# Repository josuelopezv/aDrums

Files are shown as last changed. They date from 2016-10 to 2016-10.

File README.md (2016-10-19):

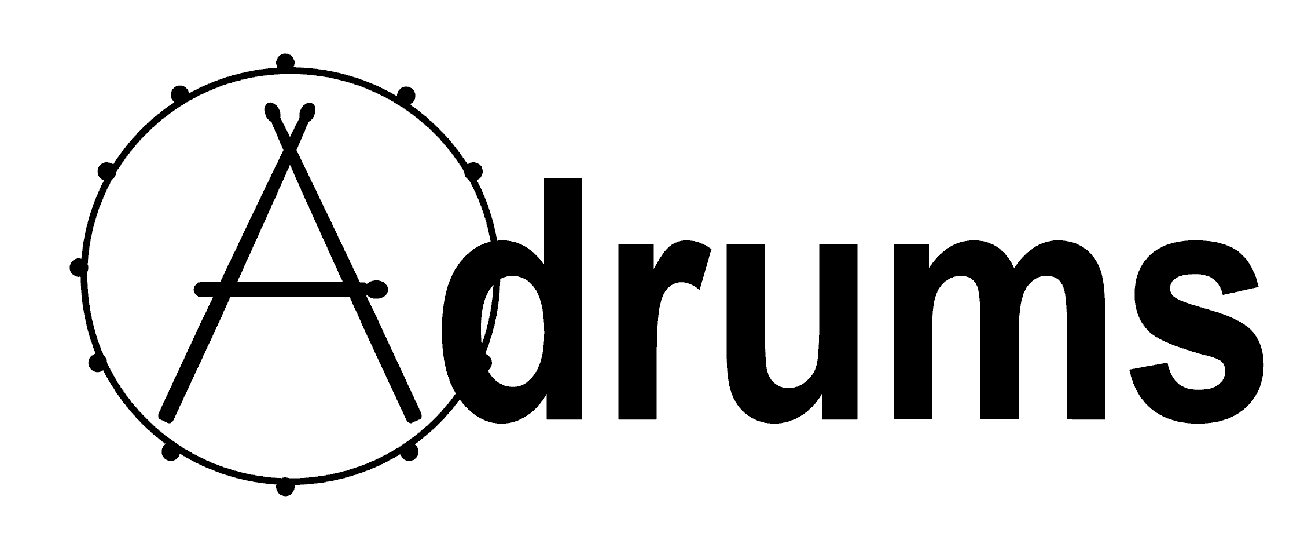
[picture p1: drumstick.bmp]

[]()

**A-Drums** is a completly Open Source, Advance Drum MIDI Trigger based on Arduino Leonardo Micro Pro. The idea came after seeing solutions like MegaDRUM but it was closed source. The hardware is open source as well including Eagle Schematics and Eagle Board Layout. It is easy to use and build while being a robust product.

## Features
* 37 Input Triggers with 18 small audio jack connectors
* It's a simple USB Device without need to install any drivers to run it reports as a MIDI Device
* Positional sensing
* Fully Customizable
* Small Form Factor
* Comes with a nice easy to use GUI Manager
* Saves settings to EEPROM
* Compatible with EZ Drummer, Addictive Drums, Fruity Loops, etc.
* Cross Platform (Windows/Linux/Mac)
* Can be configured from Android or iOS

## Price and Bill of Materials
- [Arduino Leonardo Pro Micro](https://www.sparkfun.com/products/12640)		$4.13
- PCB Board		$8.30
- [Audio Jacks](http://www.ebay.com/itm/141778008302?_trksid=p2060353.m2749.l2649&ssPageName=STRK%3AMEBIDX%3AIT)		$6.87
- [Rest of electronics]		$2.5

### Total **$19.24**

I will be adding tutorials on how to build the DIY 3D Printed Drum Set, how to connect with EZ Drummer and Addictive Drums using ASIO4ALL, and aDrums Manager User Manual

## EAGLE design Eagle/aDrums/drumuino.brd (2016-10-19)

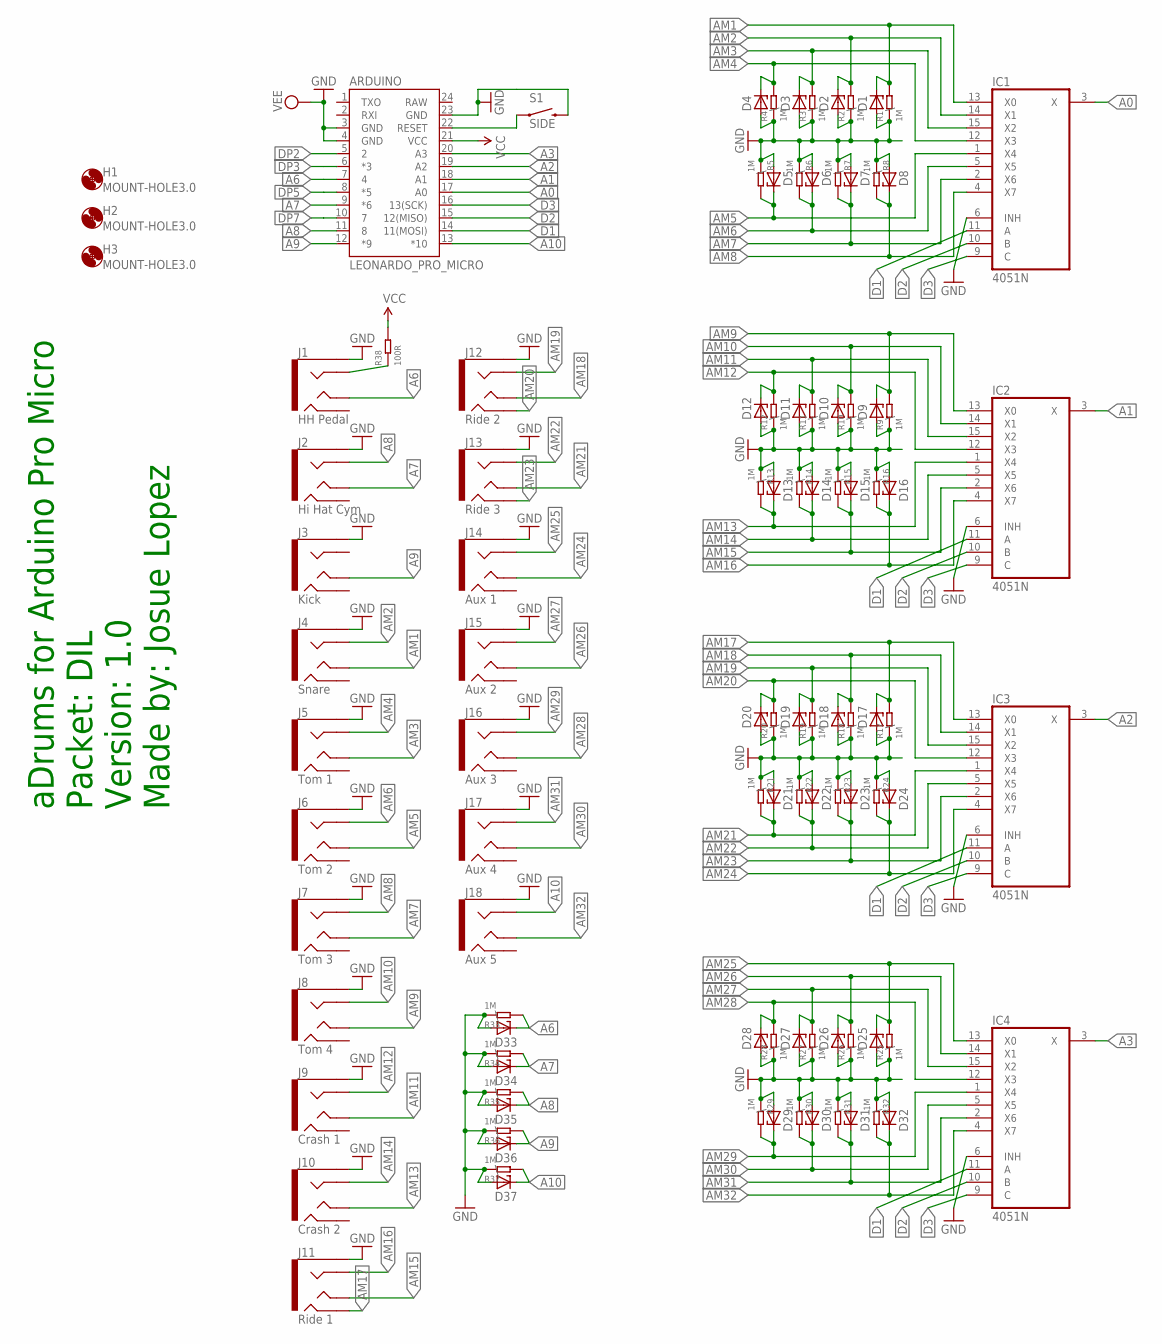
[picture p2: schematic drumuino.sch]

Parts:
ARDUINO: LEONARDO_PRO_MICRO; ARDUINO_PRO_MICRO
D1, D2, D3, D4, D5, D6, D7, D8, D9, D10, D11, D12, D13, D14, D15, D16, D17, D18, D19, D20, D21, D22, D23, D24, D25, D26, D27, D28, D29, D30, D31, D32, D33, D34, D35, D36, D37: \; DO41-7.6
H1, H2, H3: MOUNT-HOLE3.0; 3,0
IC1, IC2, IC3, IC4: 4051N; DIL16
J1: HH Pedal; AUDIO-JACK-TRRS-DIL
J2: Hi Hat Cym; AUDIO-JACK-TRRS-DIL
J3: Kick; AUDIO-JACK-TRRS-DIL
J4: Snare; AUDIO-JACK-TRRS-DIL
J5: Tom 1; AUDIO-JACK-TRRS-DIL
J6: Tom 2; AUDIO-JACK-TRRS-DIL
J7: Tom 3; AUDIO-JACK-TRRS-DIL
J8: Tom 4; AUDIO-JACK-TRRS-DIL
J9: Crash 1; AUDIO-JACK-TRRS-DIL
J10: Crash 2; AUDIO-JACK-TRRS-DIL
J11: Ride 1; AUDIO-JACK-TRRS-DIL
J12: Ride 2; AUDIO-JACK-TRRS-DIL
J13: Ride 3; AUDIO-JACK-TRRS-DIL
J14: Aux 1; AUDIO-JACK-TRRS-DIL
J15: Aux 2; AUDIO-JACK-TRRS-DIL
J16: Aux 3; AUDIO-JACK-TRRS-DIL
J17: Aux 4; AUDIO-JACK-TRRS-DIL
J18: Aux 5; AUDIO-JACK-TRRS-DIL
R1, R2, R3, R4, R5, R6, R7, R8, R9, R10, R11, R12, R13, R14, R15, R16, R17, R18, R19, R20, R21, R22, R23, R24, R25, R26, R27, R28, R29, R30, R31, R32, R33, R34, R35, R36, R37: 1M; R0207_7
R38: 100R; R0207_7
S1: SIDE; TACTILE-PTH-SIDEEZ

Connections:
A0: ARDUINO.17 (A0), IC1.3 (X)
A1: ARDUINO.18 (A1), IC2.3 (X)
A2: ARDUINO.19 (A2), IC3.3 (X)
A3: ARDUINO.20 (A3), IC4.3 (X)
A6: ARDUINO.7 (4), D33.C, J1.TIP, R33.2
A7: ARDUINO.9 (*6), D34.C, J2.TIP, R34.2
A8: ARDUINO.11 (8), D35.C, J2.RING1, R35.2
A9: ARDUINO.12 (*9), D36.C, J3.TIP, R36.2
A10: ARDUINO.13 (*10), D37.C, J18.RING1, R37.2
AM1: D1.C, IC1.13 (X0), J4.TIP, R1.2
AM2: D2.C, IC1.14 (X1), J4.RING1, R2.2
AM3: D3.C, IC1.15 (X2), J5.TIP, R3.2
AM4: D4.C, IC1.12 (X3), J5.RING1, R4.2
AM5: D5.C, IC1.1 (X4), J6.TIP, R5.2
AM6: D6.C, IC1.5 (X5), J6.RING1, R6.2
AM7: D7.C, IC1.2 (X6), J7.TIP, R7.2
AM8: D8.C, IC1.4 (X7), J7.RING1, R8.2
AM9: D9.C, IC2.13 (X0), J8.TIP, R9.2
AM10: D10.C, IC2.14 (X1), J8.RING1, R10.2
AM11: D11.C, IC2.15 (X2), J9.TIP, R11.2
AM12: D12.C, IC2.12 (X3), J9.RING1, R12.2
AM13: D13.C, IC2.1 (X4), J10.TIP, R13.2
AM14: D14.C, IC2.5 (X5), J10.RING1, R14.2
AM15: D15.C, IC2.2 (X6), J11.TIP, R15.2
AM16: D16.C, IC2.4 (X7), J11.RING1, R16.2
AM17: D17.C, IC3.13 (X0), J11.RING2, R17.2
AM18: D18.C, IC3.14 (X1), J12.TIP, R18.2
AM19: D19.C, IC3.15 (X2), J12.RING1, R19.2
AM20: D20.C, IC3.12 (X3), J12.RING2, R20.2
AM21: D21.C, IC3.1 (X4), J13.TIP, R21.2
AM22: D22.C, IC3.5 (X5), J13.RING1, R22.2
AM23: D23.C, IC3.2 (X6), J13.RING2, R23.2
AM24: D24.C, IC3.4 (X7), J14.TIP, R24.2
AM25: D25.C, IC4.13 (X0), J14.RING1, R25.2
AM26: D26.C, IC4.14 (X1), J15.TIP, R26.2
AM27: D27.C, IC4.15 (X2), J15.RING1, R27.2
AM28: D28.C, IC4.12 (X3), J16.TIP, R28.2
AM29: D29.C, IC4.1 (X4), J16.RING1, R29.2
AM30: D30.C, IC4.5 (X5), J17.TIP, R30.2
AM31: D31.C, IC4.2 (X6), J17.RING1, R31.2
AM32: D32.C, IC4.4 (X7), J18.TIP, R32.2
D1: ARDUINO.14 (11(MOSI)), IC1.11 (A), IC2.11 (A), IC3.11 (A), IC4.11 (A)
D2: ARDUINO.15 (12(MISO)), IC1.10 (B), IC2.10 (B), IC3.10 (B), IC4.10 (B)
D3: ARDUINO.16 (13(SCK)), IC1.9 (C), IC2.9 (C), IC3.9 (C), IC4.9 (C)
DP2: ARDUINO.5 (2)
DP3: ARDUINO.6 (*3)
DP5: ARDUINO.8 (*5)
DP7: ARDUINO.10 (7)
GND: ARDUINO.3 (GND), ARDUINO.4 (GND), ARDUINO.23 (GND), D1.A, D2.A, D3.A, D4.A, D5.A, D6.A, D7.A, D8.A, D9.A, D10.A, D11.A, D12.A, D13.A, D14.A, D15.A, D16.A, D17.A, D18.A, D19.A, D20.A, D21.A, D22.A, D23.A, D24.A, D25.A, D26.A, D27.A, D28.A, D29.A, D30.A, D31.A, D32.A, D33.A, D34.A, D35.A, D36.A, D37.A, IC1.6 (INH), IC1.7 (VEE), IC1.8 (GND), IC2.6 (INH), IC2.7 (VEE), IC2.8 (GND), IC3.6 (INH), IC3.7 (VEE), IC3.8 (GND), IC4.6 (INH), IC4.7 (VEE), IC4.8 (GND), J1.2EARTH (EARTH), J1.EARTH, J2.2EARTH (EARTH), J2.EARTH, J3.2EARTH (EARTH), J3.EARTH, J4.2EARTH (EARTH), J4.EARTH, J5.2EARTH (EARTH), J5.EARTH, J6.2EARTH (EARTH), J6.EARTH, J7.2EARTH (EARTH), J7.EARTH, J8.2EARTH (EARTH), J8.EARTH, J9.2EARTH (EARTH), J9.EARTH, J10.2EARTH (EARTH), J10.EARTH, J11.2EARTH (EARTH), J11.EARTH, J12.2EARTH (EARTH), J12.EARTH, J13.2EARTH (EARTH), J13.EARTH, J14.2EARTH (EARTH), J14.EARTH, J15.2EARTH (EARTH), J15.EARTH, J16.2EARTH (EARTH), J16.EARTH, J17.2EARTH (EARTH), J17.EARTH, J18.2EARTH (EARTH), J18.EARTH, R1.1, R2.1, R3.1, R4.1, R5.1, R6.1, R7.1, R8.1, R9.1, R10.1, R11.1, R12.1, R13.1, R14.1, R15.1, R16.1, R17.1, R18.1, R19.1, R20.1, R21.1, R22.1, R23.1, R24.1, R25.1, R26.1, R27.1, R28.1, R29.1, R30.1, R31.1, R32.1, R33.1, R34.1, R35.1, R36.1, R37.1, S1.2
HHC_TIP: J1.RING1, R38.1
unnamed: ARDUINO.22 (RESET), S1.1
VCC: ARDUINO.21 (VCC), IC1.16 (VCC), IC2.16 (VCC), IC3.16 (VCC), IC4.16 (VCC), R38.2

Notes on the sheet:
aDrums for Arduino Pro Micro Packet: DIL Version: 1.0 Made by: Josue Lopez

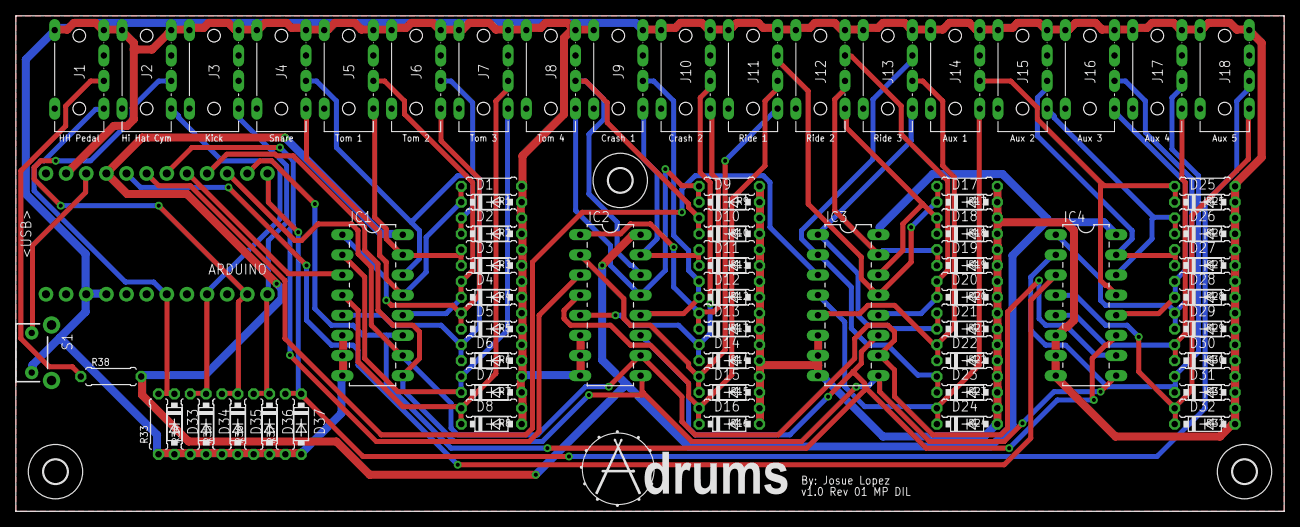
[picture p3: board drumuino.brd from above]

Board: 2 copper layers, 160.0 x 62.5 mm, 102 parts (0 on the bottom side), 48 nets.

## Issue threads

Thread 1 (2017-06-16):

Documentation? Video demonstration?

j, 2017-06-16:
Are you still using this? And if so, do you have a demo online?

josuelopezv, 2017-06-17:
Hi,

Yes this is working but it was still under development but anything you
need i can help you

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

j, 2017-06-20:
It'd be cool to have direct links of what exactly all is needed as well as instalation of this library.  I have a new custom accoustic kit being made right now and going to order r-drum triggers and jobeky cymbals, etc, but would like to hack away at this using my pearl e-Pro just to get a feel.

What hardware do I need exactly?

Thanks!

j, 2017-06-20:
Also, have you tried this with something like Kontakt 5?  The Jay Maas signature series sampling from RoomSound is so nice. https://www.youtube.com/watch?v=6PCLWqnZ0bA

MisterY, 2017-06-21:
Yes, please! Some documentation in the wiki would be fantastic. I'll try to work out some on my own, of course, and contribute via fork.
Other than that, I'd like to show you a link to [Open Source Drum Module](https://sites.google.com/view/open-source-drum-module) project. Basicall, it's a site where I'm trying to collect various pieces, work out some standards, and present multiple end-options by combining various components together. OK, this sounds too abstract but practically means that one should be able to have an open source drum module by using their PC for home practice, as well as having a separate enclosed module for professional use.
Well, have a look at the text and let me know where it can be improved. I could also initially help by writing some documentation from the point of a newcomer to aDrum, which usually helps.
I clearly see that aDrum idea fully aligns with OSDM.

josuelopezv, 2017-06-23:
Hi All,

thanks for the interest in my project. I started this project because i had
the need of something like mega drums (http://www.megadrum.info) so I
created an open source version of it. I have not had the chance to finish
the docs or upload any demo although most of the project was fully
functional I was waiting to finish it if someone wants to help me that will
be great. I finish the hardware and firmware and only missing part is 30%
of the development of the software to upload the config files to the
hardware.

On Wed, Jun 21, 2017 at 3:18 AM, Alen Siljak <notifications@github.com>
wrote:

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

MisterY, 2017-06-23:
Fantastic! I'm certainly volunteering to help. I can't promise a whole lot of time but I can say that we definitely share exactly the same goal.
There are a few others who made some progress on the hardware part and this can be followed [here](https://www.vdrums.com/forum/advanced/diy/1154514-thinking-of-building-my-own-module).
I see that the software was built with Visual Studio so that should not be a problem.

Do you have any schematics you could share? I'd like to eventually have a prototype with a breadboard and Arduino Mega, that I could use to test everything.
I could immediately focus on the missing part - the upload of the config files to the hardware. It's just that I'd need to test with actual hardware. :)

j, 2017-07-17:
Food for thought: keeping the software OS but having a paid hardware.. I'd buy that over building it myself and just hack on software side.  Easier way to get into the code.  I just bought the Pearl Mimic Pro though...

josuelopezv, 2017-07-17:
the schematics were uploaded on the project as well. it is a simple arduino
with multiplexer to expand the inputs

On Mon, Jul 17, 2017 at 1:18 PM, Jordan Stout <notifications@github.com>
wrote:

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

MisterY, 2017-07-18:
Hi, @josuelopezv, could you post a link to the schematics, please? I see no new commits so they must be elsewhere? Looking forward to hack a bit with this.
Thanks!

josuelopezv, 2017-07-19:
https://github.com/josuelopezv/aDrums/blob/master/Eagle/aDrums/drumuino.sch

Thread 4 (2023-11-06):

Positional sensing - How?

eriksonssilva, 2023-11-06:
Hey @josuelopezv ! Thanks a lot for enriching the opensource world with such amazing project!
I'm wondering if you would be able telling us how to achieve positional sensing on a Snare pad?
Images/video would be awesome, but I know that you may not have them at hand, so a written description would help already.
Thanks a lot once again!

josuelopezv, 2023-11-08:
Hi this protect is deprecated but i can guide you on how to get positional sending on the snare pad. Normally compatible e drum snares have a sensor in the center and 1 or more in the ring. Basically depending on the sensor reading frecuency you calculate the delay on the signal on each sensor and get the position the snare was hit. First a calibration reading is needed where the user hits the center of the drum so the system gets the baseline delay on the rim sensor and then hit the rim to get the baseline of the center sensor. Then just adjust depending on the reading delays

eriksonssilva, 2023-11-08:
Hey Josue! Thanks a lot for your answer on this!
Ok, I get the overall picture.
Have you tried this with VST's such as Ez Drummer / Superior Drummer or any of those?
And last question: Would it be possible to use this with Uno/Mega with proper adjustments? I think yes, but I did not dive too deep.
Thanks!

eriksonssilva, 2023-11-08:
Reading through the github page, I see you mention that the editor should be used for editing - and I assume it should also be used for "calibration", am I right?
However, I did not se any release for the apps. Should I build it myself? Sorry, C/C# are languages I'm not familiar!

josuelopezv, 2023-11-08:
This can be achieved with arduino uno however stm32 or new arduino micro or leonardo compatible boards are faster (more cycles for reading from the ADC) for the same price as arduino uno. The VST that you choose doesn't affect, all of them use midi as the input so this is universal

josuelopezv, 2023-11-08:
Yes the editor is to control the firmware for arduino device, what sensors are connected, what type of sensor and the parameters. This is saved on the eeprom of the arduino and the firmware converts the information received by the sensot to a midi note that any VST reads and play the corresponding sound

eriksonssilva, 2023-11-08:
> This can be achieved with arduino uno however stm32 or new arduino micro or leonardo compatible boards are faster (more cycles for reading from the ADC) for the same price as arduino uno. The VST that you choose doesn't affect, all of them use midi as the input so this is universal

Ok, cool! I'll see if I can order a Leonardo then!

eriksonssilva, 2023-11-08:
> Yes the editor is to control the firmware for arduino device, what sensors are connected, what type of sensor and the parameters. This is saved on the eeprom of the arduino and the firmware converts the information received by the sensor to a midi note that any VST reads and play the corresponding sound

Yeah, I think I understood this part! The only thing is tricky is that I don't see an exe or whatever so I can use on my computer.
So I'm assuming I have to build that or something like that?

josuelopezv, 2023-11-08:
you can download the code and compile win.aDrumsManager it will generate the exe file that contains the manager that will install the firmware on your arduino and be able to configure it

eriksonssilva, 2023-11-08:
Ok, I'll try to compile it here.
I've tried a bit but got several errors lol
I'll let you know if I need further assistance.
Thanks a lot, man! Have a good day!

eriksonssilva, 2023-11-08:
Closing since nothing else needs to be done on @josuelopezv end.

eriksonssilva, 2023-11-08:
Ok, I hate to be THAT guy. But I've downloaded Visual Studio and updated everything needed.
However, when compiling the file, this is all I see:
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

I know that my port is COM4, so I simply delete the COM1 and press "button2", but then I see this:

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

`See the end of this message for details on invoking
just-in-time (JIT) debugging instead of this dialog box.

************** Exception Text **************
System.Exception: Programmer Port not found
   at aDrumsLib.AvrUploader.Upload(String comPort, String UploaderExePath, String configFilePath, String HexFilePath) in C:\Users\Erikson\Desktop\aDrums-master\aDrumsLib\ArduinoUploader.cs:line 36
   at aDrumsLib.AvrUploader.Upload(String comPort) in C:\Users\Erikson\Desktop\aDrums-master\aDrumsLib\ArduinoUploader.cs:line 45
   at aDrumsLib.AvrUploader.Upload() in C:\Users\Erikson\Desktop\aDrums-master\aDrumsLib\ArduinoUploader.cs:line 54
   at aDrum.Form1.button2_Click(Object sender, EventArgs e) in C:\Users\Erikson\Desktop\aDrums-master\win.aDrumsManager\Form1.cs:line 43
   at System.Windows.Forms.Control.OnClick(EventArgs e)
   at System.Windows.Forms.Button.OnClick(EventArgs e)
   at System.Windows.Forms.Button.OnMouseUp(MouseEventArgs mevent)
   at System.Windows.Forms.Control.WmMouseUp(Message& m, MouseButtons button, Int32 clicks)
   at System.Windows.Forms.Control.WndProc(Message& m)
   at System.Windows.Forms.ButtonBase.WndProc(Message& m)
   at System.Windows.Forms.Button.WndProc(Message& m)
   at System.Windows.Forms.Control.ControlNativeWindow.OnMessage(Message& m)
   at System.Windows.Forms.Control.ControlNativeWindow.WndProc(Message& m)
   at System.Windows.Forms.NativeWindow.Callback(IntPtr hWnd, Int32 msg, IntPtr wparam, IntPtr lparam)

************** Loaded Assemblies **************
mscorlib
    Assembly Version: 4.0.0.0
    Win32 Version: 4.8.9181.0 built by: NET481REL1LAST_C
    CodeBase: file:///C:/Windows/Microsoft.NET/Framework/v4.0.30319/mscorlib.dll
----------------------------------------
aDrum
    Assembly Version: 1.0.0.0
    Win32 Version: 1.0.0.0
    CodeBase: file:///C:/Users/Erikson/Desktop/aDrums-master/win.aDrumsManager/bin/Debug/aDrum.exe
----------------------------------------
System.Windows.Forms
    Assembly Version: 4.0.0.0
    Win32 Version: 4.8.9181.0 built by: NET481REL1LAST_C
    CodeBase: file:///C:/Windows/Microsoft.Net/assembly/GAC_MSIL/System.Windows.Forms/v4.0_4.0.0.0__b77a5c561934e089/System.Windows.Forms.dll
----------------------------------------
System
    Assembly Version: 4.0.0.0
    Win32 Version: 4.8.9172.0 built by: NET481REL1LAST_C
    CodeBase: file:///C:/Windows/Microsoft.Net/assembly/GAC_MSIL/System/v4.0_4.0.0.0__b77a5c561934e089/System.dll
----------------------------------------
System.Drawing
    Assembly Version: 4.0.0.0
    Win32 Version: 4.8.9037.0 built by: NET481REL1
    CodeBase: file:///C:/Windows/Microsoft.Net/assembly/GAC_MSIL/System.Drawing/v4.0_4.0.0.0__b03f5f7f11d50a3a/System.Drawing.dll
----------------------------------------
System.Configuration
    Assembly Version: 4.0.0.0
    Win32 Version: 4.8.9037.0 built by: NET481REL1
    CodeBase: file:///C:/Windows/Microsoft.Net/assembly/GAC_MSIL/System.Configuration/v4.0_4.0.0.0__b03f5f7f11d50a3a/System.Configuration.dll
----------------------------------------
System.Core
    Assembly Version: 4.0.0.0
    Win32 Version: 4.8.9200.0 built by: NET481REL1LAST_C
    CodeBase: file:///C:/Windows/Microsoft.Net/assembly/GAC_MSIL/System.Core/v4.0_4.0.0.0__b77a5c561934e089/System.Core.dll
----------------------------------------
System.Xml
    Assembly Version: 4.0.0.0
    Win32 Version: 4.8.9037.0 built by: NET481REL1
    CodeBase: file:///C:/Windows/Microsoft.Net/assembly/GAC_MSIL/System.Xml/v4.0_4.0.0.0__b77a5c561934e089/System.Xml.dll
----------------------------------------
Accessibility
    Assembly Version: 4.0.0.0
    Win32 Version: 4.8.9037.0 built by: NET481REL1
    CodeBase: file:///C:/Windows/Microsoft.Net/assembly/GAC_MSIL/Accessibility/v4.0_4.0.0.0__b03f5f7f11d50a3a/Accessibility.dll
----------------------------------------
aDrumsLib
    Assembly Version: 1.0.0.0
    Win32 Version: 1.0.0.0
    CodeBase: file:///C:/Users/Erikson/Desktop/aDrums-master/win.aDrumsManager/bin/Debug/aDrumsLib.DLL
----------------------------------------

************** JIT Debugging **************
To enable just-in-time (JIT) debugging, the .config file for this
application or computer (machine.config) must have the
jitDebugging value set in the system.windows.forms section.
The application must also be compiled with debugging
enabled.

For example:

<configuration>
    <system.windows.forms jitDebugging="true" />
</configuration>

When JIT debugging is enabled, any unhandled exception
will be sent to the JIT debugger registered on the computer
rather than be handled by this dialog box.

`

Any ideas why this is happening? I've tried googling and chatgpt, but nothing seems to help.

Thanks and sorry once again!

eriksonssilva, 2023-11-08:
Oh, and pressing button 1 immediately closes the program.

snx778, 2024-03-27:
> this is all I see

@eriksonssilva, and i think that's all. I compiled the windows app and i saw the same (while the web app wasn't working at all), so i hope the author of the project will finish the work or at least explain us how to use the existing software to configure the module :)

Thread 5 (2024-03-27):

How to build webapp?

snx778, 2024-03-27:
Can't properly build webapp. Last try ended up with this exception:

`System.IO.FileNotFoundException: Could not load file or assembly "Microsoft.AspNetCore.Hosting.Abstractions, Version=1.1.3.0, Culture=neutral, PublicKeyToken=adb9793829ddae60" or one of its dependencies. The specified module could not be found.
`
although the package was installed...

I've tried many things to deal with it, but i just don't understand what's wrong.

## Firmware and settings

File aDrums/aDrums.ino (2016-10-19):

#include "DrumPins.h"
#include <MIDIUSB.H>
#include <EEPROM.h>

#define VersionMajor 1
#define VersionMinor 0

#pragma region arrays
byte pinLocation[MAX_PIN_SIZE] = {
	getPinLoc(A6	,	0),	//	HiHat Pedal
	getPinLoc(A7	,	0),	//	HiHat Cymbal T
	getPinLoc(A8	,	0),	//	HiHat Cymbal R
	getPinLoc(A9	,	0),	//	Kick Drum
	getPinLoc(A0	,	0),	//	Snare T
	getPinLoc(A0	,	1),	//	Snare R
	getPinLoc(A0	,	2),	//	Tom 1 T
	getPinLoc(A0	,	3),	//	Tom 1 R
	getPinLoc(A0	,	4),	//	Tom 2 T
	getPinLoc(A0	,	5),	//	Tom 2 R
	getPinLoc(A0	,	6),	//	Tom 3 T
	getPinLoc(A0	,	7),	//	Tom 3 R
	getPinLoc(A1	,	0),	//	Tom 4 T
	getPinLoc(A1	,	1),	//	Tom 4 R
	getPinLoc(A1	,	2),	//	Crash 1 T
	getPinLoc(A1	,	3),	//	Crash 1 R
	getPinLoc(A1	,	4),	//	Crash 2 T
	getPinLoc(A1	,	5),	//	Crash 2 R
	getPinLoc(A1	,	6),	//	Ride 1 T
	getPinLoc(A1	,	7),	//	Ride 1 R
	getPinLoc(A2	,	0),	//	Ride 1 S
	getPinLoc(A2	,	1),	//	Ride 2 T
	getPinLoc(A2	,	2),	//	Ride 2 R
	getPinLoc(A2	,	3),	//	Ride 2 S
	getPinLoc(A2	,	4),	//	Ride 3 T
	getPinLoc(A2	,	5),	//	Ride 3 R
	getPinLoc(A2	,	6),	//	Ride 3 S
	getPinLoc(A2	,	7),	//	Aux 1 T
	getPinLoc(A3	,	0),	//	Aux 1 R
	getPinLoc(A3	,	1),	//	Aux 2 T
	getPinLoc(A3	,	2),	//	Aux 2 R
	getPinLoc(A3	,	3),	//	Aux 3 T
	getPinLoc(A3	,	4),	//	Aux 3 R
	getPinLoc(A3	,	5),	//	Aux 4 T
	getPinLoc(A3	,	6),	//	Aux 4 R
	getPinLoc(A3	,	7),	//	Aux 5 T
	getPinLoc(A10	,	0),	//	Aux 5 R
};
byte pinType[MAX_PIN_SIZE];
byte pinThreshold[MAX_PIN_SIZE];
byte pinNoteOnThreshold[MAX_PIN_SIZE];
byte pinNoteOnValue[MAX_PIN_SIZE];
byte pinPitch[MAX_PIN_SIZE];
#pragma endregion

#pragma region Setups
void setup() {
	EEPROM_Load();
	setupADC();
	setupSerial();
}
// set up funcs
void setupADC() {
	// Define various ADC prescaler
	//------------------------------
	const unsigned char PS_16 = (1 << ADPS2);
	//const unsigned char PS_32 = (1 << ADPS2) | (1 << ADPS0);
	//const unsigned char PS_64 = (1 << ADPS2) | (1 << ADPS1);
	const unsigned char PS_128 = (1 << ADPS2) | (1 << ADPS1) | (1 << ADPS0);

	//http://www.microsmart.co.za/technical/2014/03/01/advanced-arduino-adc/
	ADCSRA &= ~PS_128;  // remove bits set by Arduino library
	ADCSRA |= PS_16;    // set our own prescaler to 16 for ~20 us
}
#pragma endregion

#pragma region Serial
#define BAUD_RATE 115200
#define MAX_DATA_BYTES          7 // max number of data bytes in incoming messages
#define START_SYSEX             0xF0 // start a MIDI Sysex message
#define END_SYSEX               0xF7 // end a MIDI Sysex message

byte storedInputData[MAX_DATA_BYTES]; // multi-byte data for SysEx
int sysexBytesRead = 0;
boolean parsingSysex = false;

void setupSerial() {
	Serial.begin(BAUD_RATE);
	while (!Serial);
	Serial.print("Welcome to aDrums v");
	Serial.print(VersionMajor);
	Serial.print(".");
	Serial.print(VersionMinor);
}

void processSerialInput() {
	while (Serial.available()) {
		int inputData = Serial.read(); // this is 'int' to handle -1 when no data
		if (inputData != -1) {
			parse(inputData);
		}
	}
}
void parse(byte inputData) {
	if (parsingSysex)
	{
		if (inputData == END_SYSEX)
		{
			//stop sysex byte
			parsingSysex = false;
			//fire off handler function
			processSysexMessage();
		}
		else
		{
			//normal data byte - add to buffer
			storedInputData[sysexBytesRead] = inputData;
			sysexBytesRead++;
		}
	}
	else if (inputData == START_SYSEX)
	{
		parsingSysex = true;
		sysexBytesRead = 0;
	}
}
void processSysexMessage() {
	sysexCallback(storedInputData[0], sysexBytesRead - 1, storedInputData + 1);
}

void TX_SERIAL(byte command, byte pin, int value) {
	Serial.write(START_SYSEX);
	Serial.write(command);
	Serial.write(pin);
	Serial.write(value);
	Serial.write(END_SYSEX);
	Serial.flush();
}
#pragma endregion

#pragma region Loops
void loop()
{
	processSerialInput();
	readPins();
}
#pragma endregion

#pragma region MIDI
#define DEFAULT_CHANNEL 0
// First parameter is the event type (0x09 = note on, 0x08 = note off).
// Second parameter is note-on/note-off, combined with the channel.
// Channel can be anything between 0-15. Typically reported to the user as 1-16.
// Third parameter is the note number (48 = middle C).
// Fourth parameter is the velocity (64 = normal, 127 = fastest).
void noteOn(byte channel, byte pitch, byte velocity) {
	midiEventPacket_t noteOn = { 0x09, 0x90 | channel, pitch, velocity };
	MidiUSB.sendMIDI(noteOn);
}
void noteOff(byte channel, byte pitch, byte velocity) {
	midiEventPacket_t noteOff = { 0x08, 0x80 | channel, pitch, velocity };
	MidiUSB.sendMIDI(noteOff);
}
// First parameter is the event type (0x0B = control change).
// Second parameter is the event type, combined with the channel.
// Third parameter is the control number number (0-119).
// Fourth parameter is the control value (0-127).
void controlChange(byte channel, byte control, byte value) {
	midiEventPacket_t event = { 0x0B, 0xB0 | channel, control, value };
	MidiUSB.sendMIDI(event);
}
#pragma endregion

#pragma region ReadDrums
void readPins() {
	for (byte i = 0; i < MAX_PIN_SIZE; i++)
	{
		switch (pinType[i])
		{
		case PINTYPE_DISABLED:
			break;
		default:
			ReadDrum(i, getAnalogueValue(i));
			break;
		}
	}
}
int getAnalogueValue(byte pin) {
	byte location = pinLocation[pin];
	digitalWrite(ADCD1, (location & FLAG_IC1) ? HIGH : LOW);  //flag 00000001
	digitalWrite(ADCD2, (location & FLAG_IC2) ? HIGH : LOW);  //flag 00000010
	digitalWrite(ADCD3, (location & FLAG_IC3) ? HIGH : LOW);  //flag 00000100
	return	analogRead((location >> 3));
}
void ReadDrum(byte pin, int value) {
	if (value >= pinThreshold[pin])
	{
		if (pinNoteOnValue[pin] == 0)
			noteOn(DEFAULT_CHANNEL, pinPitch[pin], getVelocity(pin, value));

		pinNoteOnValue[pin]++;
	}
	else if (pinNoteOnValue[pin] > 0 && pinNoteOnValue[pin] > pinNoteOnThreshold[pin])
	{
		noteOff(DEFAULT_CHANNEL, pinPitch[pin], 0);
		pinNoteOnValue[pin] = 0;
	}
}
byte getVelocity(byte pin, int analogue_value) {
	//analogue_value max = 1023
	return (analogue_value / 8);
}
#pragma endregion

#pragma region Callbacks
#define toMSG(NAME) MSG_ ## NAME
#define caseCallBack(NAME) \
	case toMSG(NAME): \
		if(isSet) \
			  NAME [arrayPointer[0]] = arrayPointer[1]; \
		else \
			TX_SERIAL( command , arrayPointer[0], NAME [arrayPointer[0]] ); \
	break; 

#define MSG_GET_HANDSHAKE 0
#define MSG_GET_PINCOUNT 8
#define MSG_EEPROM 100
#define MSG_pinType 1
#define MSG_pinThreshold 2
#define MSG_pinNoteOnThreshold 3
#define MSG_pinPitch 4

void sysexCallback(byte command, byte size, byte* arrayPointer) {
	bool isSet = command & 1;
	switch ((command >> 1))
	{
	case MSG_GET_HANDSHAKE: TX_SERIAL(command, VersionMajor, VersionMinor); break;
	case MSG_GET_PINCOUNT: TX_SERIAL(command, MAX_PIN_SIZE, 0); break; 
	case MSG_EEPROM: if (isSet) EEPROM_Save(); else EEPROM_Load(); TX_SERIAL(command, 1, 1); break;
		caseCallBack(pinType);
		caseCallBack(pinThreshold);
		caseCallBack(pinNoteOnThreshold);
		caseCallBack(pinPitch);
	}
}

#pragma endregion

#pragma region EEPROM
#define _S_EPROM(a,b) eeprom_write_bytes((MAX_PIN_SIZE * b), a, MAX_PIN_SIZE)
#define _L_EPROM(a,b) eeprom_read_bytes((MAX_PIN_SIZE * b), a, MAX_PIN_SIZE)
#define _EPROM_StartAddr 0

void EEPROM_Save() {
	_S_EPROM(pinType, 0);
	_S_EPROM(pinThreshold, 1);
	_S_EPROM(pinNoteOnThreshold, 2);
	_S_EPROM(pinPitch, 3);
}
void EEPROM_Load() {
	_L_EPROM(pinType, 0);
	_L_EPROM(pinThreshold, 1);
	_L_EPROM(pinNoteOnThreshold, 2);
	_L_EPROM(pinPitch, 3);
}

//
// Absolute min and max eeprom addresses.
// Actual values are hardware-dependent.
//
// These values can be changed e.g. to protect
// eeprom cells outside this range.
//
const int EEPROM_MIN_ADDR = 0;
const int EEPROM_MAX_ADDR = 1023;

//
// Returns true if the address is between the
// minimum and maximum allowed values,
// false otherwise.
//
// This function is used by the other, higher-level functions
// to prevent bugs and runtime errors due to invalid addresses.
//
boolean eeprom_is_addr_ok(int addr) {
	return ((addr >= EEPROM_MIN_ADDR) && (addr <= EEPROM_MAX_ADDR));
}

//
// Writes a sequence of bytes to eeprom starting at the specified address.
// Returns true if the whole array is successfully written.
// Returns false if the start or end addresses aren't between
// the minimum and maximum allowed values.
// When returning false, nothing gets written to eeprom.
//
boolean eeprom_write_bytes(int startAddr, const byte* array, int numBytes) {
	// counter
	int i;

	// both first byte and last byte addresses must fall within
	// the allowed range  
	if (!eeprom_is_addr_ok(startAddr) || !eeprom_is_addr_ok(startAddr + numBytes)) {
		return false;
	}

	for (i = 0; i < numBytes; i++) {
		EEPROM.write(startAddr + i, array[i]);
	}

	return true;
}

//
// Reads the specified number of bytes from the specified address into the provided buffer.
// Returns true if all the bytes are successfully read.
// Returns false if the star or end addresses aren't between
// the minimum and maximum allowed values.
// When returning false, the provided array is untouched.
//
// Note: the caller must ensure that array[] has enough space
// to store at most numBytes bytes.
//
boolean eeprom_read_bytes(int startAddr, byte array[], int numBytes) {
	int i;

	// both first byte and last byte addresses must fall within
	// the allowed range  
	if (!eeprom_is_addr_ok(startAddr) || !eeprom_is_addr_ok(startAddr + numBytes)) {
		return false;
	}

	for (i = 0; i < numBytes; i++) {
		array[i] = EEPROM.read(startAddr + i);
	}

	return true;
}
#pragma endregion

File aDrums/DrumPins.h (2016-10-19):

// DrumPins.h

#ifndef _DRUMPINS_h
#define _DRUMPINS_h

//#if defined(ARDUINO) && ARDUINO >= 100
//	#include "arduino.h"
//#else
//	#include "WProgram.h"
//#endif

#define MAX_PIN_SIZE 37

//pin types
#define PINTYPE_DISABLED 0
#define PINTYPE_PIEZO 1	
#define PINTYPE_TRIMPOT 2
#define PINTYPE_SWITCH 3

#define ADCD1 PIND1
#define ADCD2 PIND2
#define ADCD3 PIND3

#define FLAG_IC1 1
#define FLAG_IC2 2
#define FLAG_IC3 4

#define getPinLoc(pin,IC_Pin) (((pin) << 3) | (IC_Pin))



#endif

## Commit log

2016-10-19 adding eagle files
    [drumuino.brd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]
2016-10-19 ver 0.9.1
    [drumuino.GBL, drumuino.GBO, drumuino.GBS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]

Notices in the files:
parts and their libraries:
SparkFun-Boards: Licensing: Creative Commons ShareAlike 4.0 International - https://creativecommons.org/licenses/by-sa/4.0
